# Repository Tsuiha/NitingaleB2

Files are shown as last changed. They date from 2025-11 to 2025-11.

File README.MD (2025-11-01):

# Nitingale B2

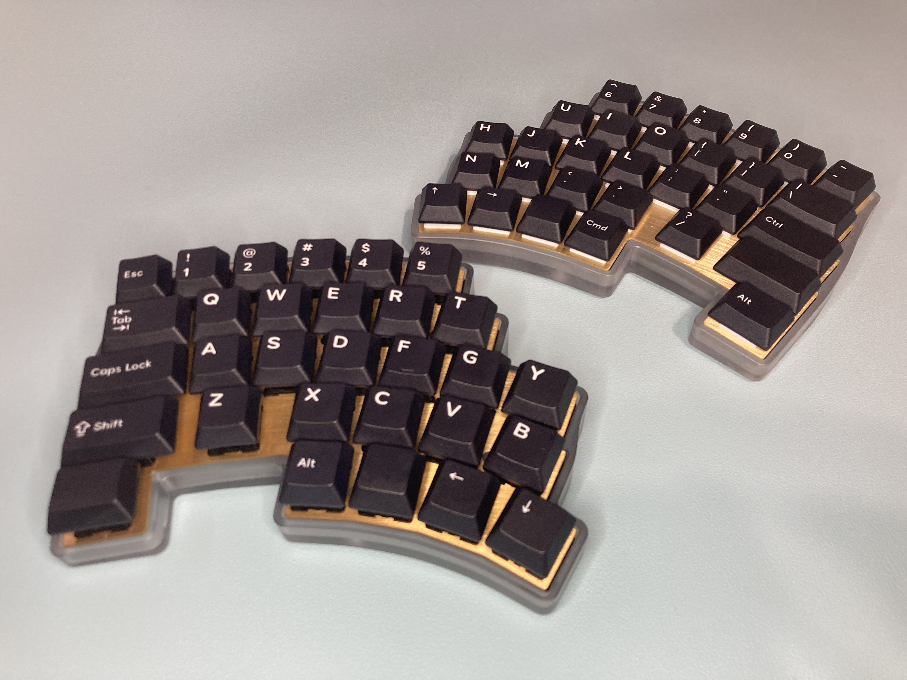
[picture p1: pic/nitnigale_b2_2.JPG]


「Nitingale B2」は、ゲーミングデバイスとして製作された左手デバイス／右手デバイスで、メカニカルスイッチを使用した自作キーボードです。

---

## 特徴

- **キー配列**  
  [Willow配列](https://coal.hatenablog.com/entry/2020/12/04/231923) や[Project mammoth](https://github.com/illness072/project-mammoth) からインスピレーションを受けてデザインされたキー配列で、無理のない指の可動域による運指をコンセプトとしています。  
  キースイッチ30個 + レバースイッチ1個の構成で、33のキー入力が可能です。

- **用途**  
  ゲーミングやアプリケーション操作を想定しており、多目的な用途に使用できるデバイスです。  
  左手用に加え、右手用もラインナップしています。

- **対応キースイッチ**  
  「Cherry MX」または「KS-33B Gateron Low Profile 3.0」に互換性のあるスイッチが使用できます。  
  キースイッチはMX用ホットスワップソケットにてPCBに接続します。

- **サイドスイッチ**  
  背面に3方向（左、右、押し込み）のレバースイッチを実装しています。  
  プロファイル切り替えやワンタッチで行いたい操作を割り振ることができます。

- **チルト／テントアングル**  
  専用ケースはチルト角6度、テント角3度の傾斜が設けられています。

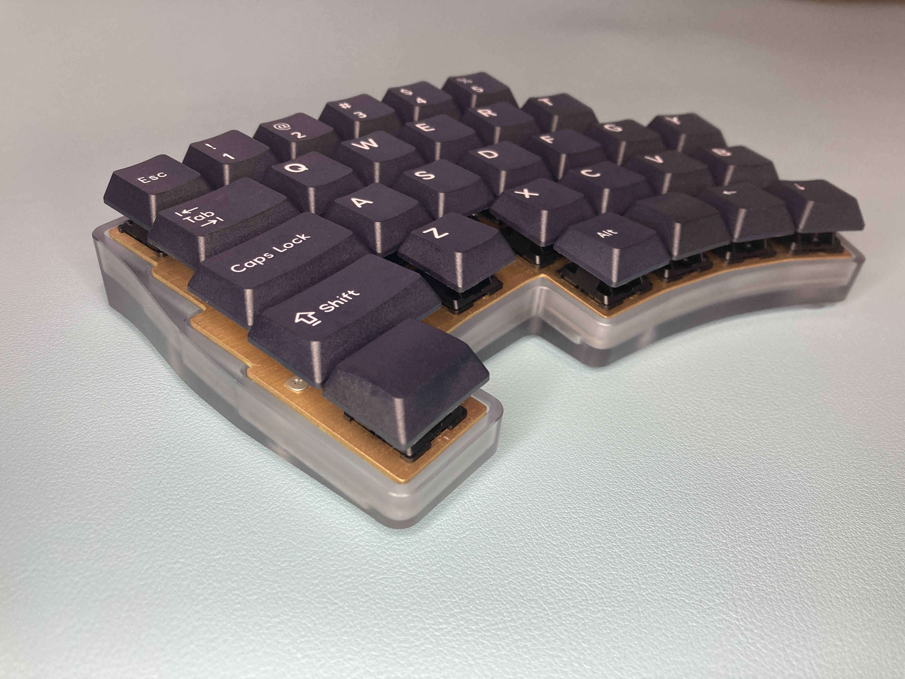
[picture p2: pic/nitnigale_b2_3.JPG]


---

## 仕様

| 項目 | 内容 |
|---|---|
| 接続 | USB Type-C（有線） |
| 入力数 | キースイッチ30入力／レバースイッチ3入力 |
| ファームウェア | QMK Firmware, [Nitingale B2 codes](https://github.com/Tsuiha/vial-qmk/tree/vial/keyboards/0_tsuiha/nitingale_b2)  |
| 設定ソフト | Vial |

---

## 構成

`Plate` - `PCB` - `Case` の3パーツ構成で、プレートマウント方式です。  
PCBはキースイッチを介してプレートに固定され、プレートはスタンドオフスペーサを介してケースに固定されます。

Nitingale B2 Overview

---

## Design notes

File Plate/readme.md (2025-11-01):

NitingaleB2_PLT_2d.dxf

 for laser cut
 
NitingaleB2_PLT_3d.dxf

 for cnc, 3dp

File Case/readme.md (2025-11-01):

NitingaleB2_Case

 need PLT standoff spacer
 
NitingaleB2_Case_AluCase

 included PLT standoff spacer

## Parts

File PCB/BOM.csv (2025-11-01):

bom | specification example of supplier
screw | M2x4mm slim head x14pcs WILCO FX-0000E
spacer | M2x8mm OD4mm x7pcs HIROSUGI ARB-2008
plate | t1.5mm laser cut Setsudandou
case | CNC/3DP JLCPCB
feet | OD10x2.25mm x4pcs
socket | for MX x30pcs
key switch | type MX or GLP3 x30pcs
J1 | typeC receptacle topmount 16+8pins GCT USB4105-GF-A
U1 | STM STM32F072CBT6
U2 | onsemi CM1293A-04SO
U3 | 3.3V LDO SOT23 TI TLV77133PDBVR
side switch | sp3t TMHU27 Akitsukidenshi
boot switch | C&K spst pts526
C1,C3 | 1uF Capacitor 0603(1608m)
C2 | 4.7uF Capacitor 0603(1608m)
C4-C7 | 0.1uF Capacitor 0603(1608m)
R1,R2 | 5.1kohm Resistor 0603(1608m)
R3 | 10kohm Resistor 0603(1608m)

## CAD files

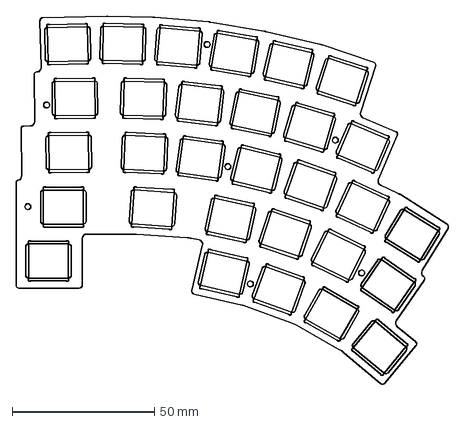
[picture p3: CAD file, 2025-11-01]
Plate/NitingaleB2_PLT_3d.dxf
152.3 x 129.6 mm

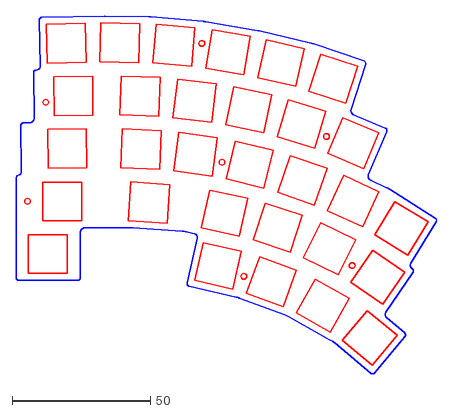
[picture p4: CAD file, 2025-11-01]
Plate/NitingaleB2_PLT_2d.dxf
152.3 x 129.5

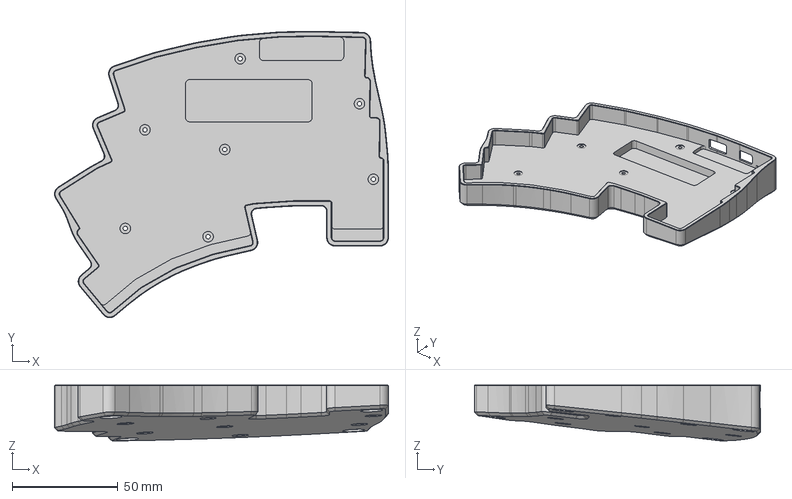
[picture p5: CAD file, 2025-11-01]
Case/250907_NitingaleB2_Case_right.step
158.2 x 135.6 x 26.5 mm

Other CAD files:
Case/250907_NitingaleB2_Case_left.step
Case/250907_NitingaleB2_AluCase_left.step
Case/250907_NitingaleB2_AluCase_right.step
Case/250907_NitingaleB2_Case.f3d

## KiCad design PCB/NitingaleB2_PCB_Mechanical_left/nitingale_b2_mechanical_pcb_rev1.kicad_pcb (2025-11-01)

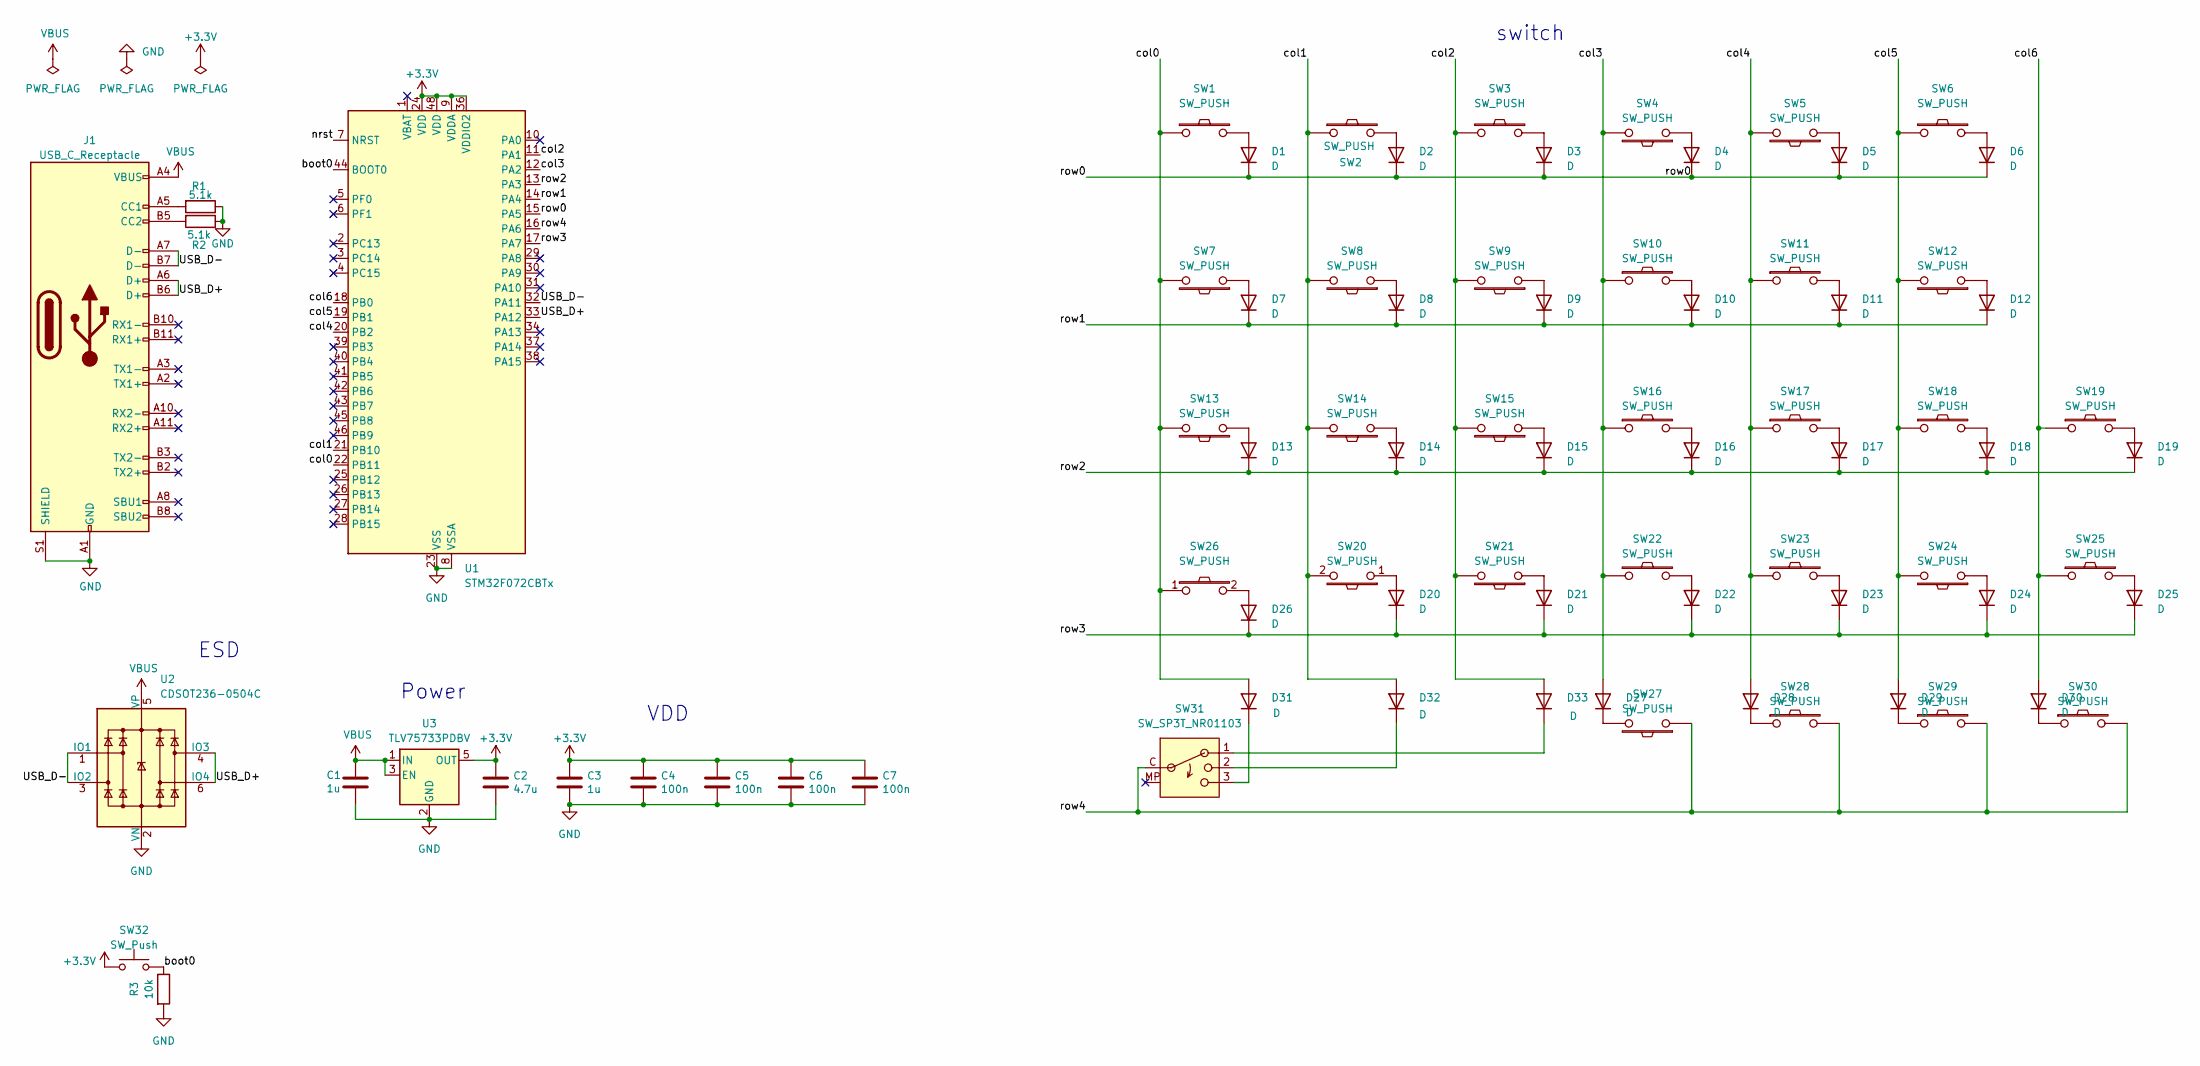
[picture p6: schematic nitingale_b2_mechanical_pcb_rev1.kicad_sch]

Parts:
C1, C3: 1u; C_0603_1608Metric
C2: 4.7u; C_0603_1608Metric
C4, C5, C6, C7: 100n; C_0603_1608Metric
D1, D2, D3, D4, D5, D6, D7, D8, D9, D10, D11, D12, D13, D14, D15, D16, D17, D18, D19, D20, D21, D22, D23, D24, D25, D26, D27, D28, D29, D30, D31, D32, D33: D; Diode_SMD_noname
J1: USB_C_Receptacle; USB_C_Receptacle_HRO_TYPE-C-31-M-12
R1, R2: 5.1k; C_0603_1608Metric
R3: 10k; C_0603_1608Metric
SW1, SW2, SW3, SW4, SW5, SW6, SW8, SW9, SW10, SW11, SW12, SW14, SW15, SW16, SW17, SW18, SW19, SW21, SW22, SW23, SW24, SW25, SW27, SW28, SW29, SW30: SW_PUSH; MX_GLPV3_1U
SW7: SW_PUSH; MX_GLPV3_1.5U
SW13, SW20: SW_PUSH; MX_GLPV3_1.75U
SW26: SW_PUSH; MX_GLPV3_1.25U
SW31: SW_SP3T_NR01103; TMHU27
SW32: SW_Push; SW_SPST_SKQG_WithStem
U1: STM32F072CBTx; LQFP-48_7x7mm_P0.5mm
U2: CDSOT236-0504C; sot-23-6-USBESD
U3: TLV75733PDBV; SOT-23-5

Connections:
+3.3V: C2.1, C3.1, C4.1, C5.1, C6.1, C7.1, SW32.1, U1.9 (VDDA), U1.24 (VDD), U1.36 (VDDIO2), U1.48 (VDD), U3.5 (OUT)
/USB_D+: J1.A6 (D+), J1.B6 (D+), U1.33 (PA12), U2.4 (IO3), U2.6 (IO4)
/USB_D-: J1.A7 (D-), J1.B7 (D-), U1.32 (PA11), U2.1 (IO1), U2.3 (IO2)
/boot0: R3.1, SW32.2, U1.44 (BOOT0)
/col0: D31.2 (A), SW1.1, SW7.2, SW13.2, SW26.1, U1.22 (PB11)
/col1: D32.2 (A), SW2.1, SW8.2, SW14.2, SW20.2, U1.21 (PB10)
/col2: D33.2 (A), SW3.1, SW9.2, SW15.2, SW21.2, U1.11 (PA1)
/col3: D27.2 (A), SW4.2, SW10.1, SW16.1, SW22.1, U1.12 (PA2)
/col4: D28.2 (A), SW5.2, SW11.1, SW17.1, SW23.1, U1.20 (PB2)
/col5: D29.2 (A), SW6.1, SW12.2, SW18.1, SW24.2, U1.19 (PB1)
/col6: D30.2 (A), SW19.1, SW25.1, U1.18 (PB0)
/nrst: U1.7 (NRST)
/row0: D1.1 (K), D2.1 (K), D3.1 (K), D4.1 (K), D5.1 (K), D6.1 (K), U1.15 (PA5)
/row1: D7.1 (K), D8.1 (K), D9.1 (K), D10.1 (K), D11.1 (K), D12.1 (K), U1.14 (PA4)
/row2: D13.1 (K), D14.1 (K), D15.1 (K), D16.1 (K), D17.1 (K), D18.1 (K), D19.1 (K), U1.13 (PA3)
/row3: D20.1 (K), D21.1 (K), D22.1 (K), D23.1 (K), D24.1 (K), D25.1 (K), D26.1 (K), U1.17 (PA7)
/row4: SW27.1, SW28.2, SW29.2, SW30.2, SW31.C (Common), U1.16 (PA6)
GND: C1.2, C2.2, C3.2, C4.2, C5.2, C6.2, C7.2, J1.A1 (GND), J1.A12 (GND), J1.B1 (GND), J1.B12 (GND), J1.S1 (SHIELD), R1.1, R2.1, R3.2, U1.8 (VSSA), U1.23 (VSS), U1.35 (VSS), U1.47 (VSS), U2.2 (VN), U3.2 (GND)
unnamed: D1.2 (A), SW1.2
unnamed: D2.2 (A), SW2.2
unnamed: D3.2 (A), SW3.2
unnamed: D4.2 (A), SW4.1
unnamed: D5.2 (A), SW5.1
unnamed: D6.2 (A), SW6.2
unnamed: D7.2 (A), SW7.1
unnamed: D8.2 (A), SW8.1
unnamed: D9.2 (A), SW9.1
unnamed: D10.2 (A), SW10.2
unnamed: D11.2 (A), SW11.2
unnamed: D12.2 (A), SW12.1
unnamed: D13.2 (A), SW13.1
unnamed: D14.2 (A), SW14.1
unnamed: D15.2 (A), SW15.1
unnamed: D16.2 (A), SW16.2
unnamed: D17.2 (A), SW17.2
unnamed: D18.2 (A), SW18.2
unnamed: D19.2 (A), SW19.2
unnamed: D20.2 (A), SW20.1
unnamed: D21.2 (A), SW21.1
unnamed: D22.2 (A), SW22.2
unnamed: D23.2 (A), SW23.2
unnamed: D24.2 (A), SW24.1
unnamed: D25.2 (A), SW25.2
unnamed: D26.2 (A), SW26.2
unnamed: D27.1 (K), SW27.2
unnamed: D28.1 (K), SW28.1
unnamed: D29.1 (K), SW29.1
unnamed: D30.1 (K), SW30.1
unnamed: D31.1 (K), SW31.3
unnamed: D32.1 (K), SW31.2
unnamed: D33.1 (K), SW31.1
unnamed: J1.A5 (CC1), R1.2
unnamed: J1.B5 (CC2), R2.2
VBUS: C1.1, J1.A4 (VBUS), J1.A9 (VBUS), J1.B4 (VBUS), J1.B9 (VBUS), U2.5 (VP), U3.1 (IN), U3.3 (EN)

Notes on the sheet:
Power
switch
ESD
VDD

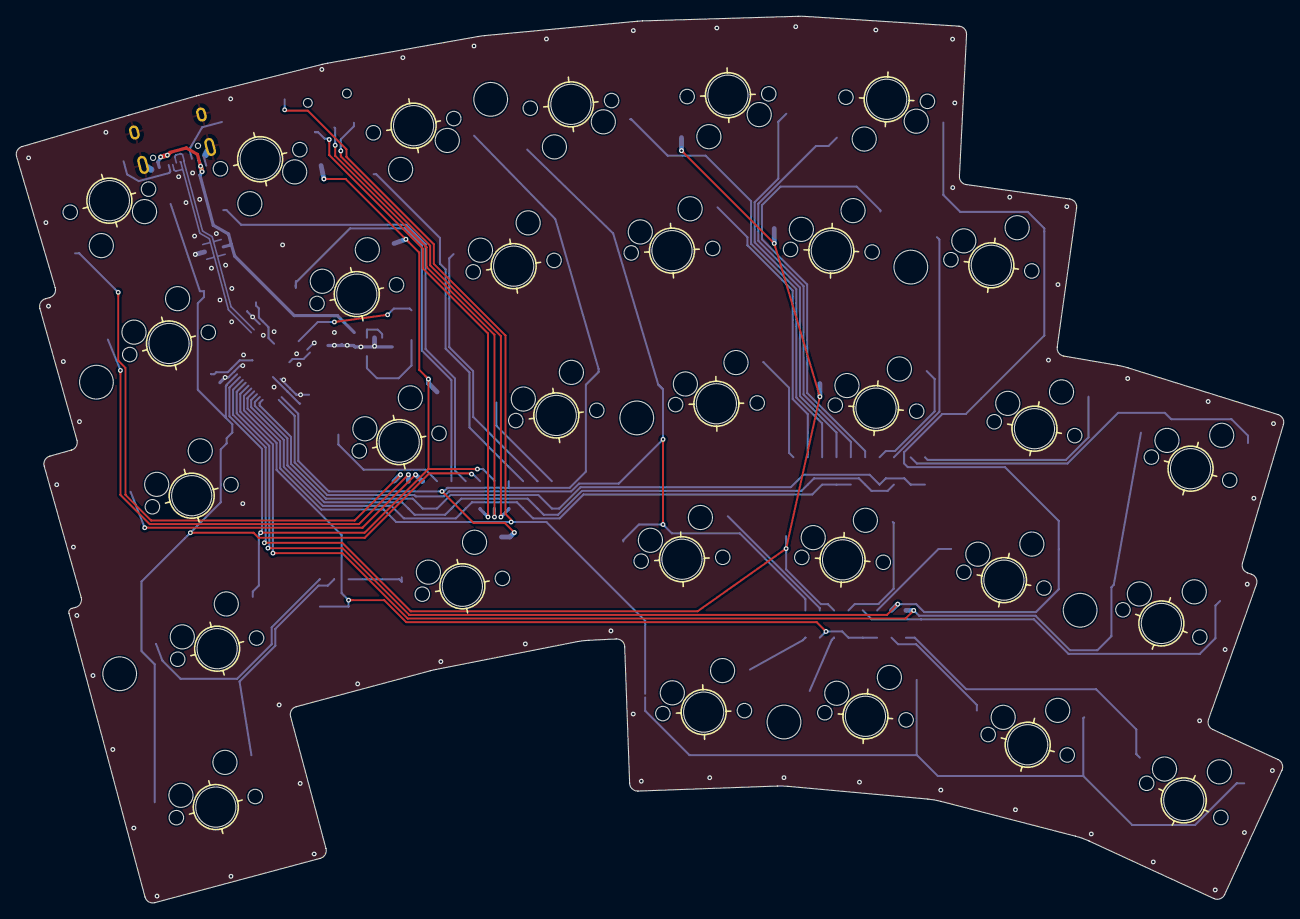
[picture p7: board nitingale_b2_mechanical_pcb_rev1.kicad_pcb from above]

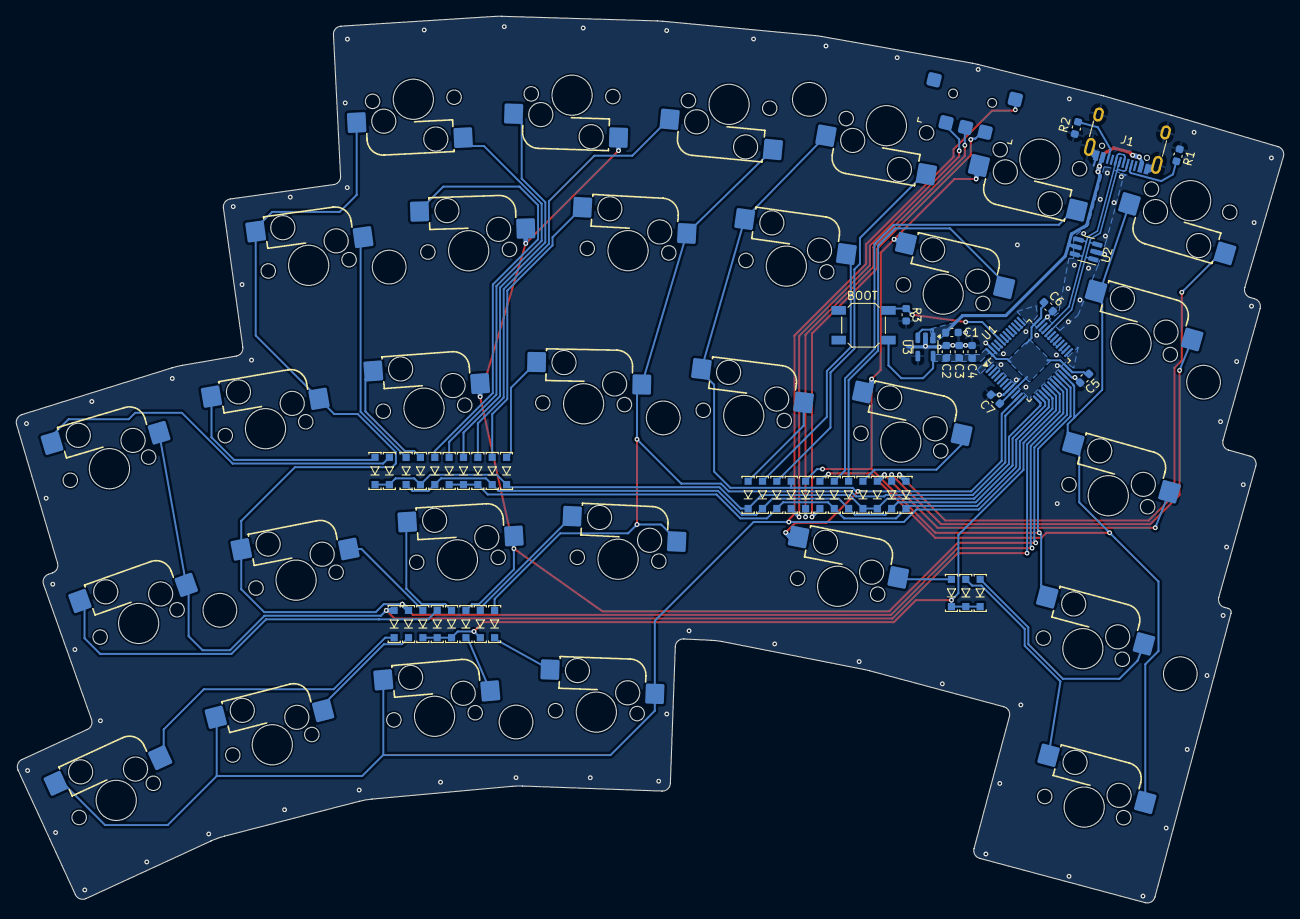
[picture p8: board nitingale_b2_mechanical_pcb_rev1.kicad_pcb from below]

Board: 2 copper layers, 157.7 x 110.3 mm, 86 parts (16 on the bottom side), 53 nets.

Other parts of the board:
Ref**: Val**; hole_4mm
Ref**#2, Ref**#3, Ref**#4, Ref**#5, Ref**#6, Ref**#7: Val**; hole_4mm
